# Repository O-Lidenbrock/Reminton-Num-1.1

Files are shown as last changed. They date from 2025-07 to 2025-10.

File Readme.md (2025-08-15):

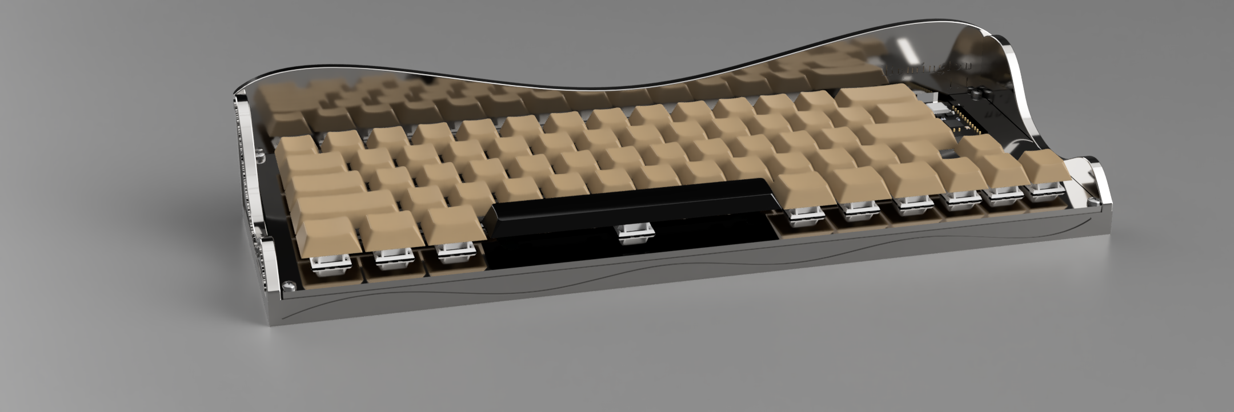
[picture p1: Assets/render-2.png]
Keyboard Render


The Remington #2 was the first typewriter with "macros" - it typed lowercase or uppercase based on whether the user was holding the Shift key. This modern, battery powered keyboard is much smaller and more portable than that original typewriter, but has lost a key. Since this layout is missing the right Shift, it's a version before the Remington #2 - the Remington #1.1

I built this to have a keyboard to use in college. Since it's battery powered, I can throw it in my backpack and use it wherever I'm studying.

> Resubmit Changes:
>
> * Designed a new base to look like a typewriter
> * Found a set of keycaps in a color scheme closer to a typewriter

### BOM

| Item | Qty | Price USD (including shipping) | Link |
|---|-----|---|---|
| Gateron Red Switches x65 | 1 | $21.34 | https://www.aliexpress.us/item/3256805364014141.html |
| Keycaps x65 | 1 | $13.50 | https://www.aliexpress.us/item/3256805435936202.html |
| PCB | 1 | $29.81 | JLCPCB |
| Diodes x65 | 1 | $1.45 | https://www.aliexpress.us/item/3256803242364455.html |
| Nice!Nano V2 | 1 | $25.00 | https://typeractive.xyz/products/nice-nano |
| Stabilizers | 1 | $2.96 | https://www.aliexpress.us/item/3256802930868859.html |
| 3D Printed Case | 1 | Free | Self-printed |
| 601230 3.7V 200mAh Battery | 1 | 12.39 | https://www.aliexpress.us/item/2251832650224851.html |
| M3 Heatset Inserts | 1 | $4.62 | https://www.aliexpress.us/item/3256804442999990.html |
| Nano Headers/Sockets | 1 | Free | From my own stock | 
Total: $111.07 USD

### Schematic
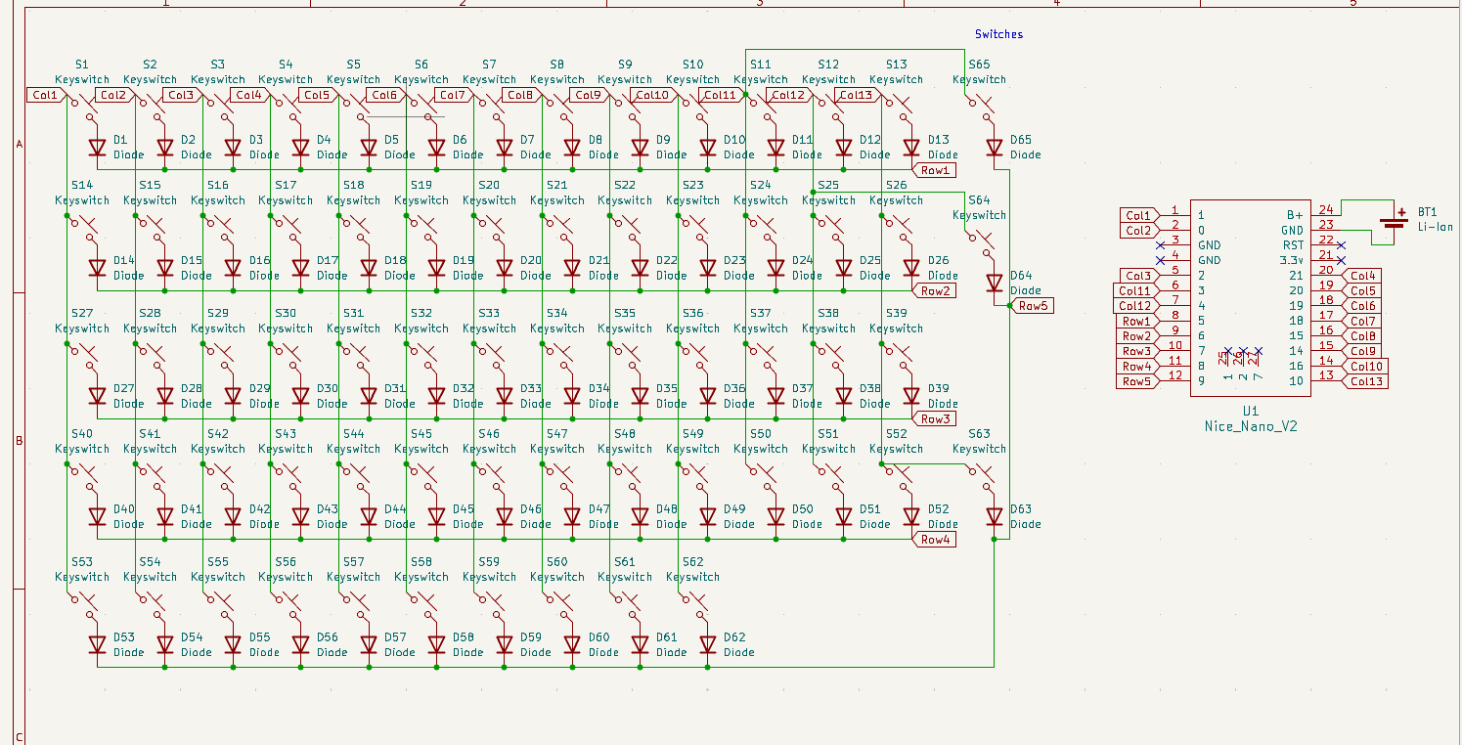
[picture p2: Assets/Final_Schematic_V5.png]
Final_Schematic_V5


### PCB
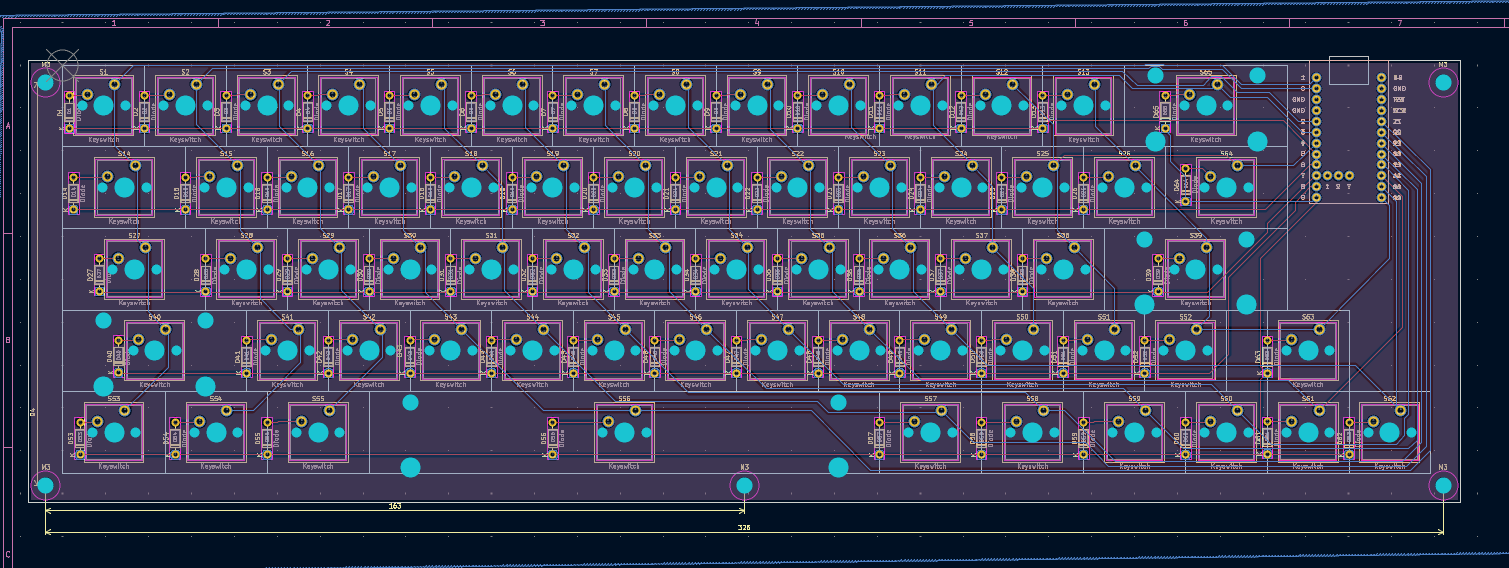
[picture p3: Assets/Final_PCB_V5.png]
Final_PCB_V5


### CAD
Base
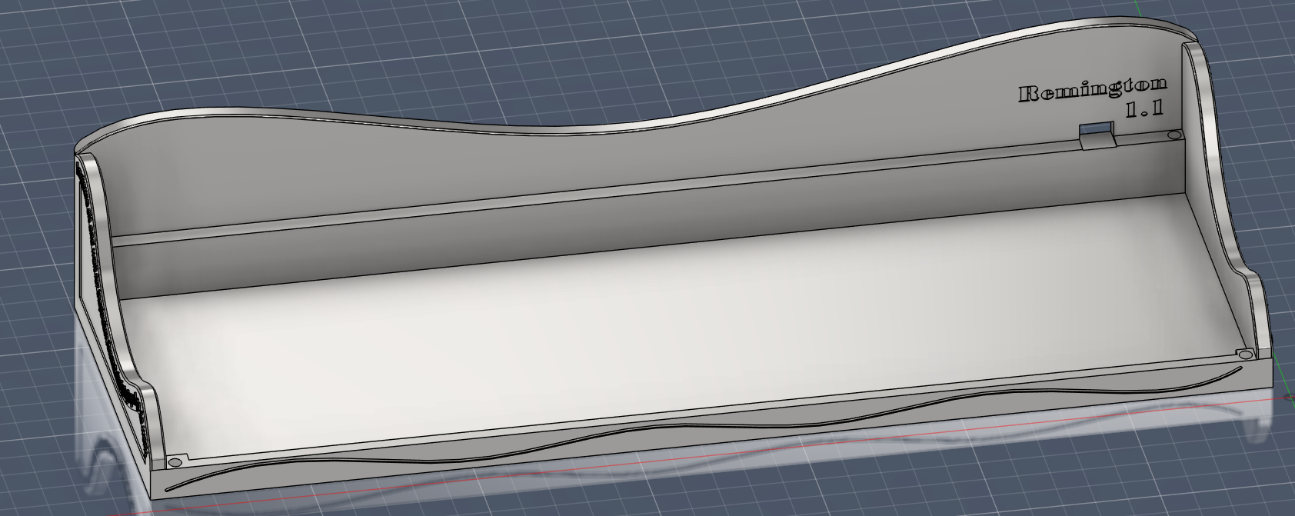
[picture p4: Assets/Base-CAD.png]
Base_CAD


Plate
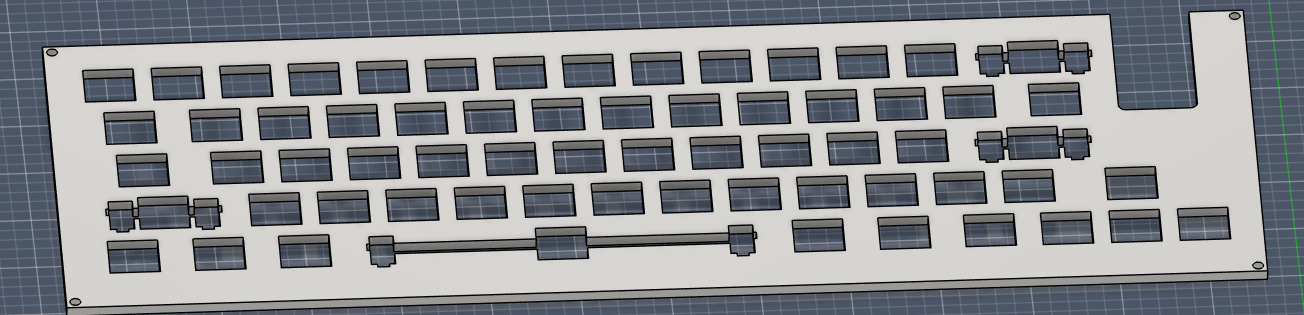
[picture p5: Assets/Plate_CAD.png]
Plate CAD


### Key Layout
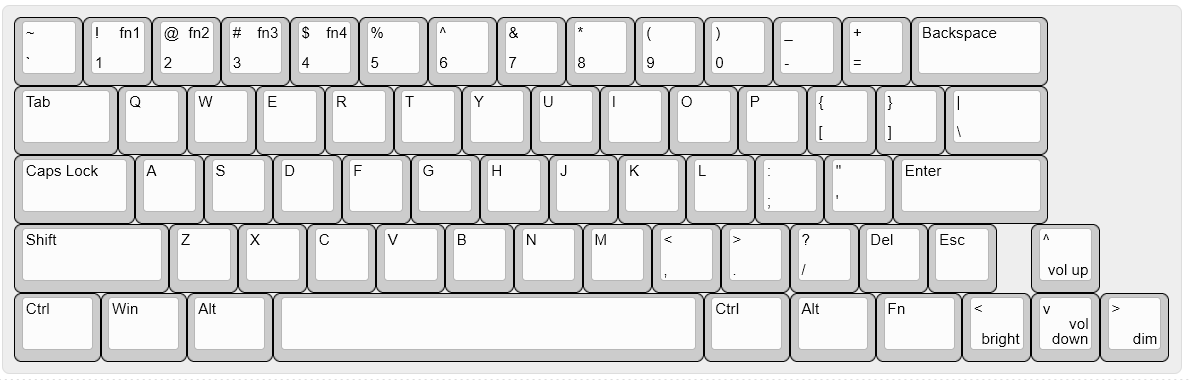
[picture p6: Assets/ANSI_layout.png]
Key layout


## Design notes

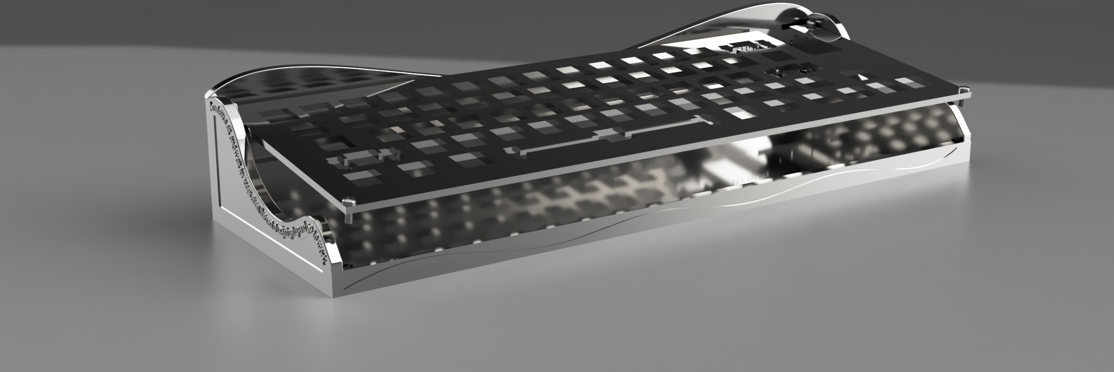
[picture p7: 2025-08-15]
Assets/CaseV4-Render.png

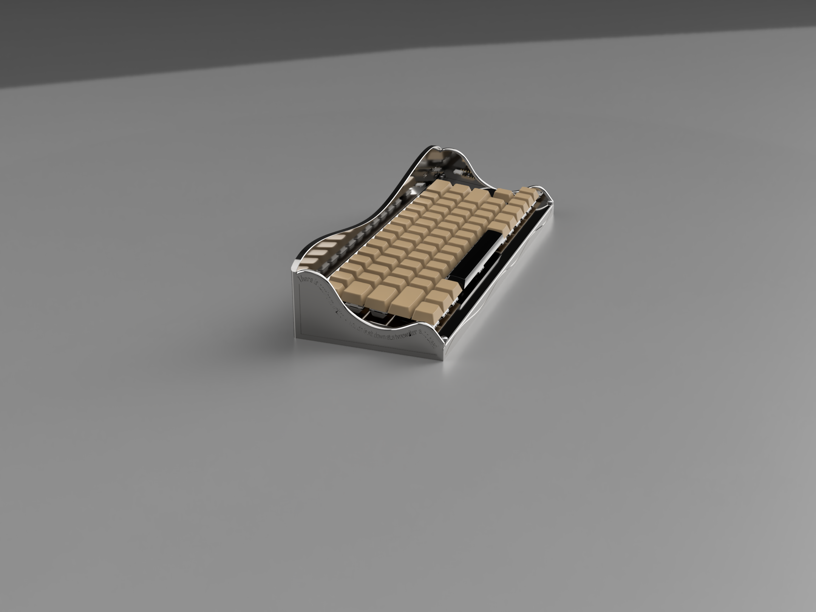
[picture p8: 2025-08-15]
Assets/Side Render.png

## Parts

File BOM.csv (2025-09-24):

Item | Qty | Price USD (including shipping) | Link
Gateron Red Switches x65 | 1 | 21.34 | https://www.aliexpress.us/item/3256805364014141.html
PCB | 1 | 29.81 | JLCPCB
Diodes x65 | 1 | 1.45 | https://www.aliexpress.us/item/3256803242364455.html
Nice!Nano V2 | 1 | 25 | https://typeractive.xyz/products/nice-nano
Stabilizers | 1 | 6.68 | https://www.aliexpress.us/item/3256806342416791.html
3D printed case | 1 | Free | Self-printed
601230 3.7V 200mAh Battery | 1 | 12.39 | https://www.aliexpress.us/item/2251832650224851.html
M3 Heatset Inserts | 1 | 4.62 | https://www.aliexpress.us/item/3256804442999990.html
Keycaps x65 (light brown) | 1 | 13.50 | https://www.aliexpress.us/item/3256805435936202.html
Nano Header | 1 | 1.23 | https://www.aliexpress.us/item/2251800479219321.html

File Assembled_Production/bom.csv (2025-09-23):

Designator | Footprint | Quantity | Value | LCSC Part #
D1, D10, D11, D12, D13, D14, D15, D16, D17, D18, D19, D2, D20, D21, D22, D23, D24, D25, D26, D27, D28, D29, D3, D30, D31, D32, D33, D34, D35, D36, D37, D38, D39, D4, D40, D41, D42, D43, D44, D45, D46, D47, D48, D49, D5, D50, D51, D52, D53, D54, D55, D56, D57, D58, D59, D6, D60, D61, D62, D63, D64, D65, D7, D8, D9 | D_SOD-123 | 65 | Diode
S1, S10, S11, S12, S13, S15, S16, S17, S18, S19, S2, S20, S21, S22, S23, S24, S25, S26, S28, S29, S3, S30, S31, S32, S33, S34, S35, S36, S37, S38, S4, S41, S42, S43, S44, S45, S46, S47, S48, S49, S5, S50, S51, S52, S6, S60, S61, S62, S63, S7, S8, S9 | SW_Cherry_MX_1.00u_PCB | 52 | Keyswitch
S14, S64 | SW_Cherry_MX_1.50u_PCB | 2 | Keyswitch
S27 | SW_Cherry_MX_1.75u_PCB | 1 | Keyswitch
S39, S40 | SW_Cherry_MX_2.25u_PCB | 2 | Keyswitch
S53, S54, S55, S57, S58, S59 | SW_Cherry_MX_1.25u_PCB | 6 | Keyswitch
S56 | SW_Cherry_MX_6.25u_PCB | 1 | Keyswitch
S65 | SW_Cherry_MX_2.00u_PCB | 1 | Keyswitch
U1 | Nice_Nano_V2 | 1 | Nice_Nano_V2

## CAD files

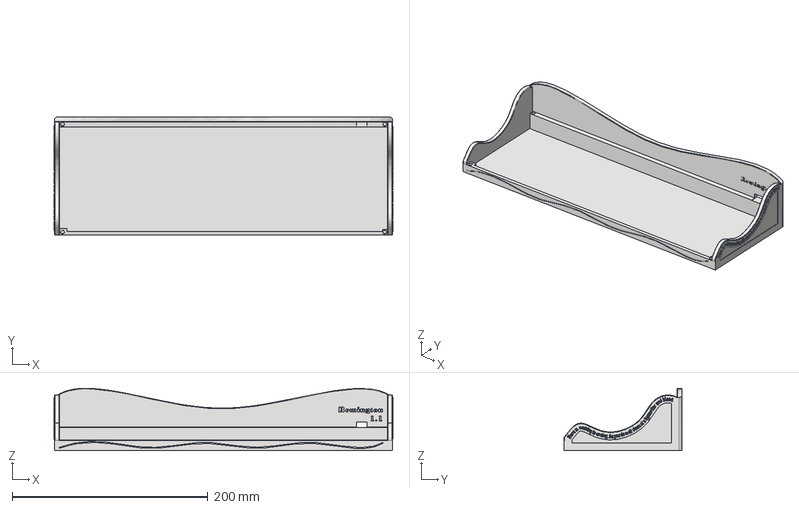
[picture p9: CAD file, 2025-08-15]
Production/Base V4 Typewriter.step
346.0 x 120.5 x 63.6 mm

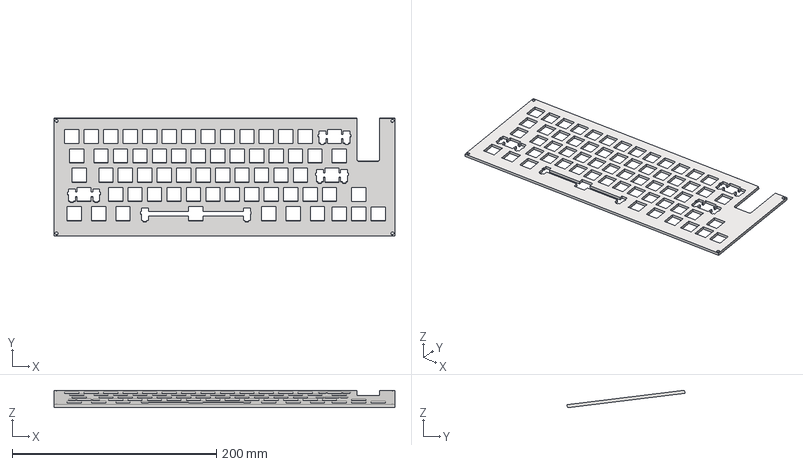
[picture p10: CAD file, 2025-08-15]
Production/Plate.step
334.0 x 115.5 x 17.1 mm

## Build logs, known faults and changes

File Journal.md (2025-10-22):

---
title: "Remington 1.1"
author: "Stephen McAllister"
description: "Custom keyboard layout: 60% with arrow keys. BLE and battery-powered."
created_at: "2025-07-03"
---

> 📘 Total Time:  33.5 hours

#### 7_3_2025 Design key layout

*1.2h* I want this to be a very small, BLE enabled, battery powered keyboard. I like the Drop Alt board design, so I'm aiming for something like that.

Getting full arrow keys (where the up/down keys aren't .5u tall) wreaks havoc with spacing. I got rid of the right shift key. 

Having func keys tertiary to the num row is fine, but I want a completely seperate esc and del key, so dropped those on the right near the arrow keys. In a final version those might just be macros.

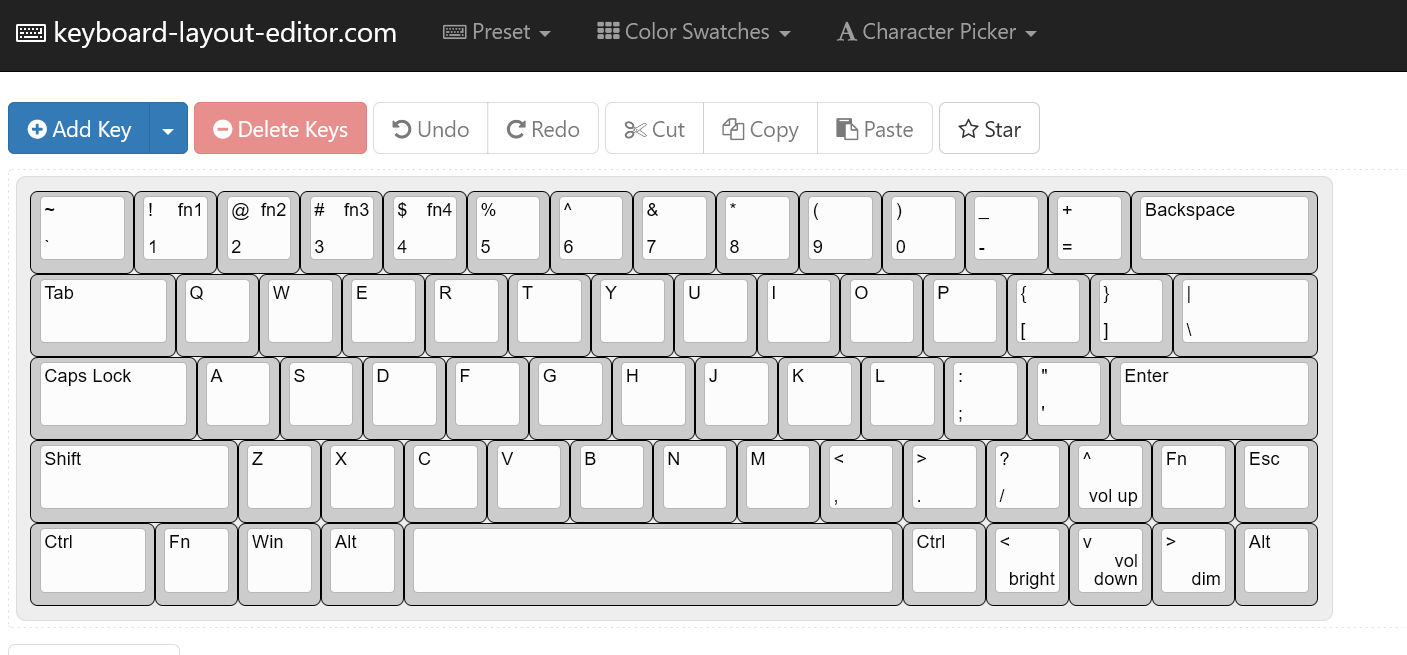
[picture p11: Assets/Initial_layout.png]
Initial Keyboard Layout


---

#### 7_15_2025 Schematic + PCB V1

*1h* Started this by laying out the switches and diodes on the schematic. I layed them out in a 14 x 5 grid, then deleted switches from the rows with fewer keys: 
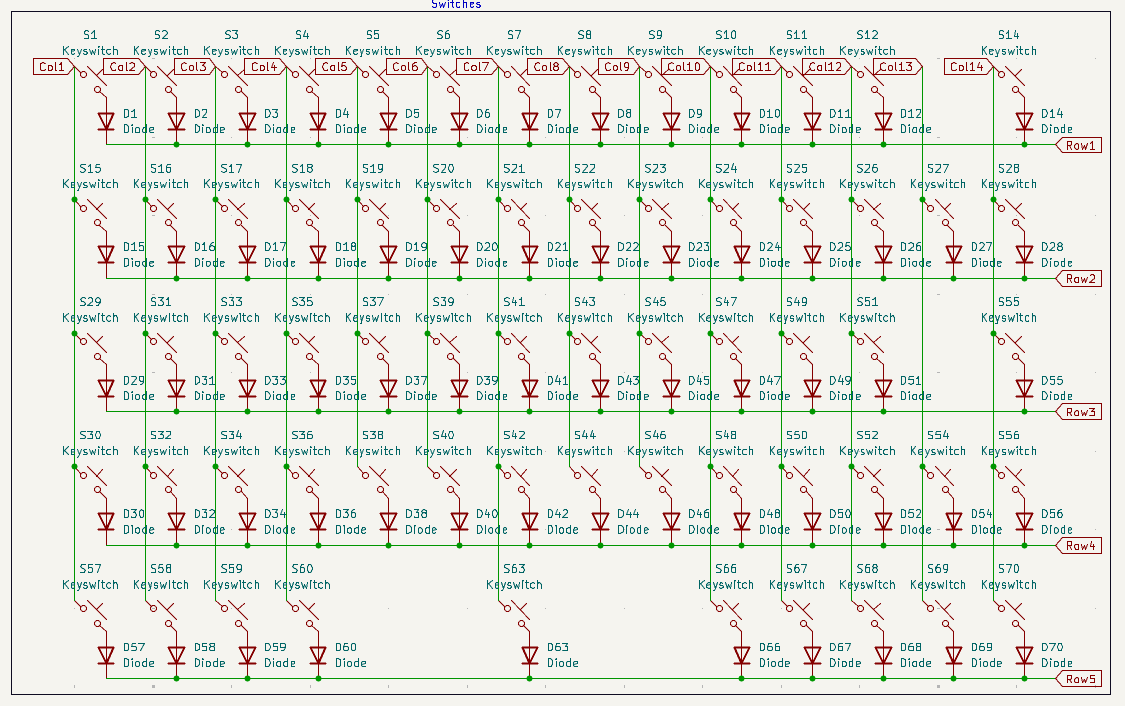
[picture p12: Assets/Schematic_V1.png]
Schematic Version 1


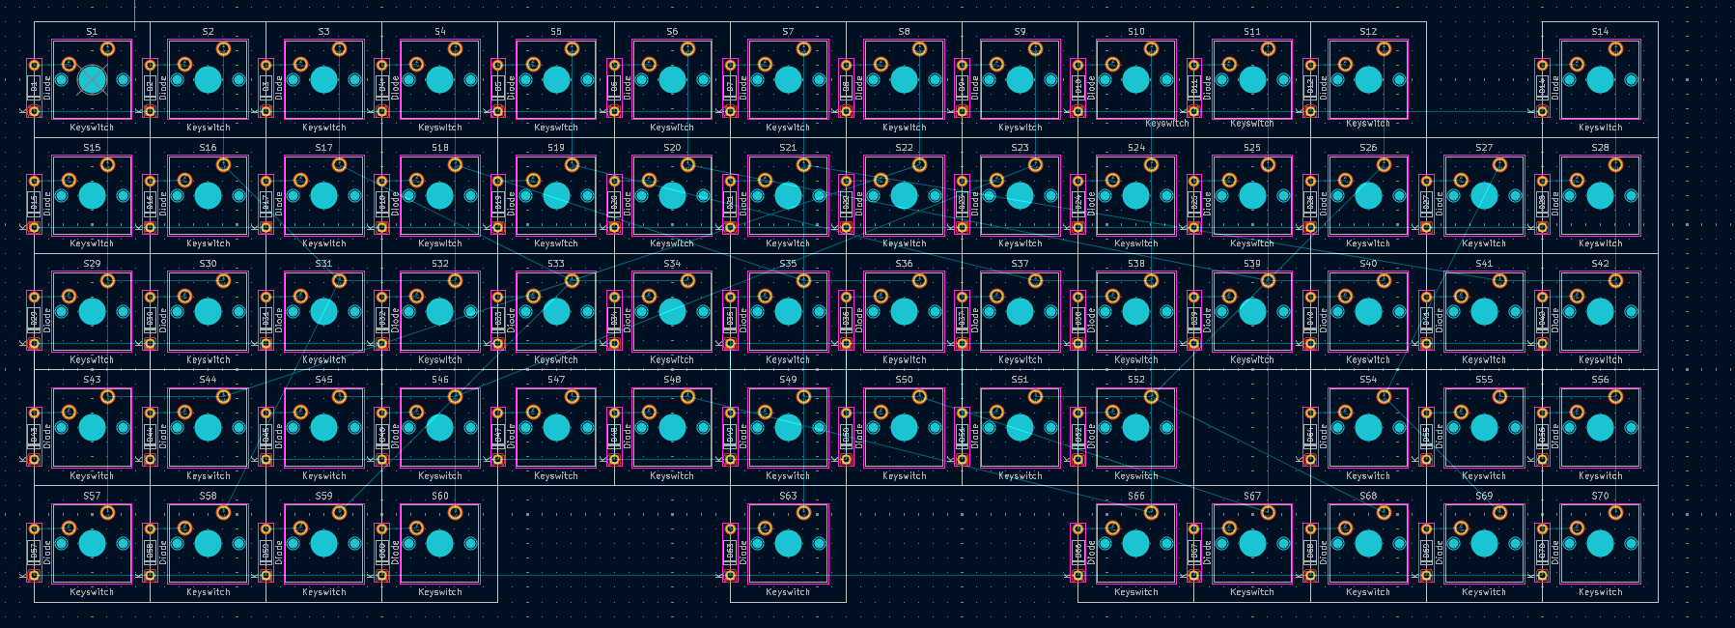
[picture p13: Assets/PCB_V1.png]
PCB Version 1
*1.5h* Once I figured out how to move the symbols on the right grid (drag them from the center pad), moving these around was pretty easy. Unfortunately I turned off the ratnest, and when I turned it back on realized the numbering was off. KiCad numbered my switches oddly when I copied and pasted on the schematic, so the last three rows of keys are all messed up. Problem for next time. 

---

#### 7_19_2025 Schematic + PCB V2

*20m* Rewrote the schematic of the switches with the right numbering. I also realized I needed one more switch in the top row, so added that. Now that I know what I'm doing, it took a lot less time.
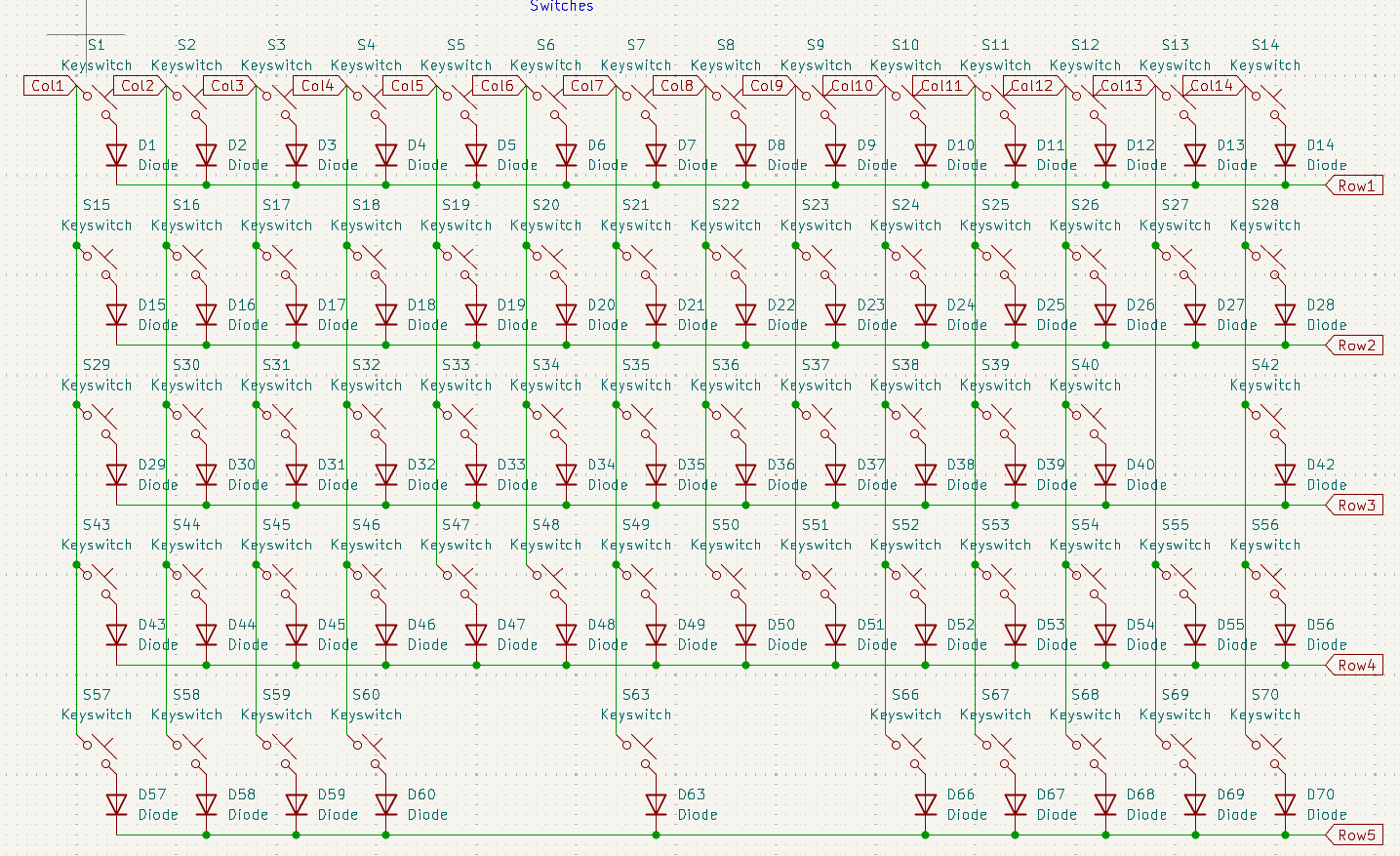
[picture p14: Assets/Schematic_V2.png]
Schematic Version 2


*4m* Updated the PCB and every switch moved to the right place! Only 13 and 53 needed to be placed. In this process I realized my original schematic was also missing switch 53, so placed that.

*20m* Change the key sizes  
I went through the schematic and changed the footprint key sizes. That's when I [found out](https://hirosarts.com/blog/keycap-dimensions-guide-for-beginners/?) that a 2.5u Shift and Caps Lock key is very hard to come by for ANSI keyboard keycap sets. I still want this pretty small, but I'll need a place for the Nano anyway, so I'm going to add the Nano to the PCB and see how the spacing works out.

*54m* Research controller boards  
This board needs bluetooth (esp32), enough pins, well-documented, and cheap. I could try a SEEED board but I'd like some arduino experience so I'm doing the Nano Esp32 with a step-up. There's also this image on one of the [docs](https://docs.arduino.cc/tutorials/nano-esp32/cheat-sheet/) showing a possible direct power from battery option. It needs EXACTLY 3.3v, though, and disables the usb-c power, so I guess I'd need a step-down in my schematic. I'll figure this out after - I know the Nano is the board I want.

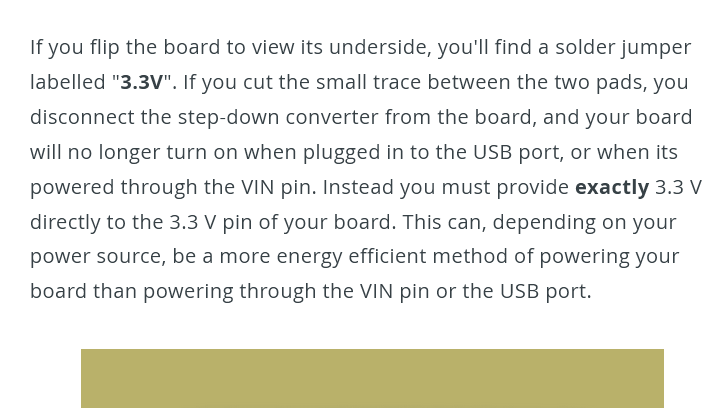
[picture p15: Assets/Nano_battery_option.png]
Arduino docs screencap


#### 7_20_2025 Schematic + PCB V3

*1.5h* Many of my keys are non-standard sizes, like the enter and caps lock which I made 2.5u. It's cheaper to buy ANSI keycaps, so I rewrote the board based on ANSI sizes. The arrows stick out, but I need a place for the board anyway so it's fine. New layout:
New ANSI Safe layout

*1h* Researched some more, and found out the Nice!Nano V2 is a very popular chip for wireless boards. Read for a while about connecting it to batteries and such.

*3h* Sooo the Nice nano only has 18 GPIO pins and I have 14 columns + 5 rows = 19 pins needed. However, I only need 65 keys: 13*5. So I'm deleting the final row and moving the keys where I need them.
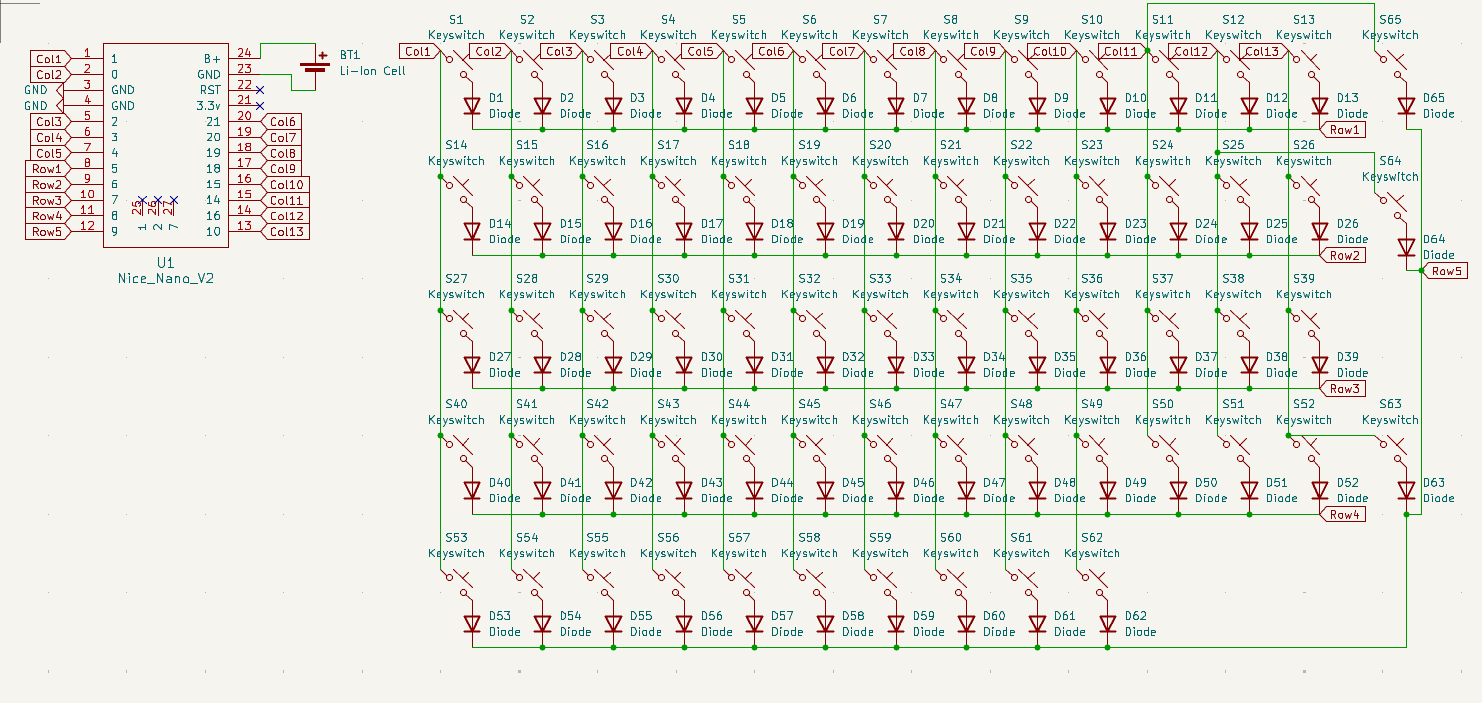
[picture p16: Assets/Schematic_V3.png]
Schematic Version 3, now 13x5


With 13 columns and 5 rows, I use all the pins. It took a while to route the individual keys, and tomorrow I'll finish by connecting lines to the board. Might need to shuffle around things to keep the rat's nest simpler.
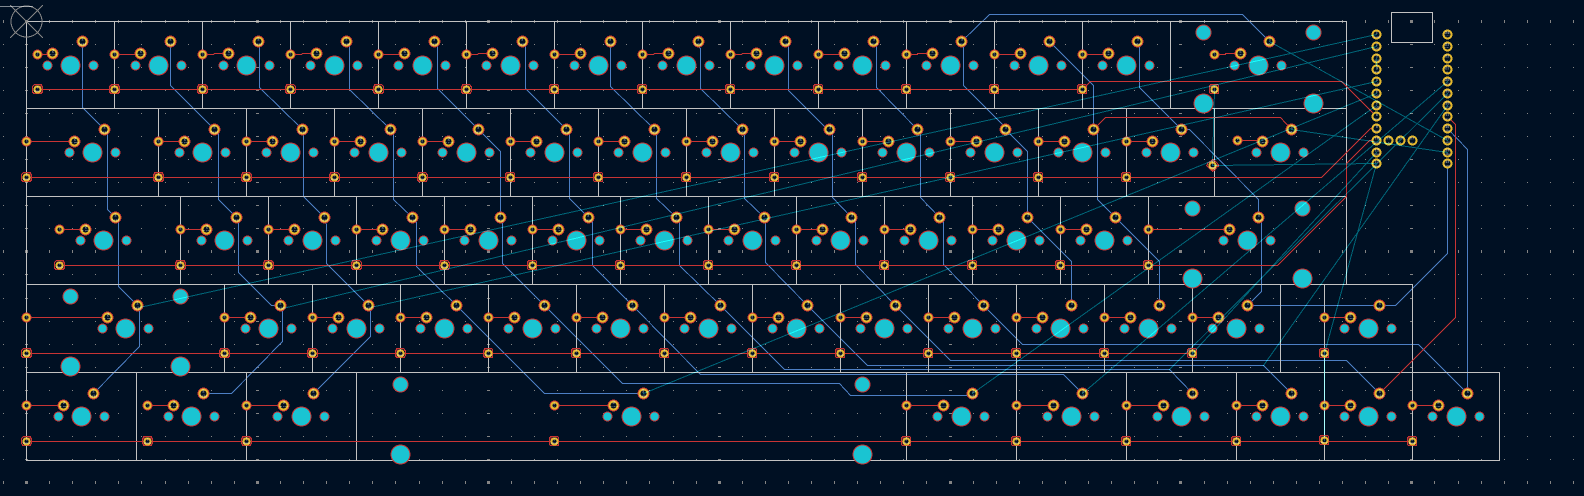
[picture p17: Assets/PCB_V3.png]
PCB editor screenshot with col and rows routed


#### 7_23_2025

*20min* Connected ratsnest to the board. It's a bit messy - might be worth shifting around pins and things.

#### 7_23_2025 Finish PCB

*1h* Fixed the ratsnest. Gave the wires correct clearance and tightened up the edges of the PCB. The stabilizer holes on the backspace button are in a really annoying position, but got around them eventually.
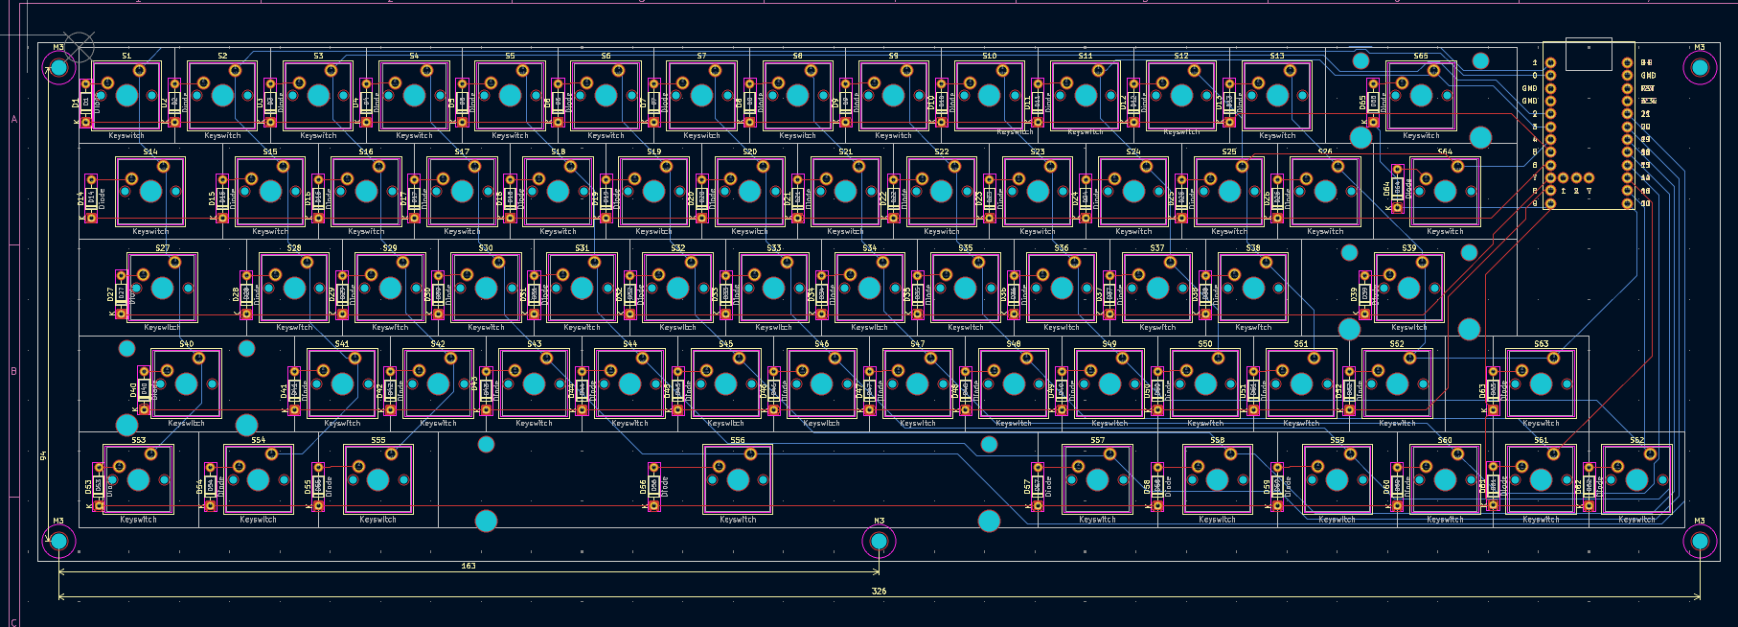
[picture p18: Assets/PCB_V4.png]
Completed PCB Wiring


#### 7_27_2025 Finish CAD

*2h* Fought with the switch model for a while, trying to figure out configurations. The final switch model has a configuration for each size of keycap, which makes it easy to switch them around on the board design. Next time I try this it will go faster
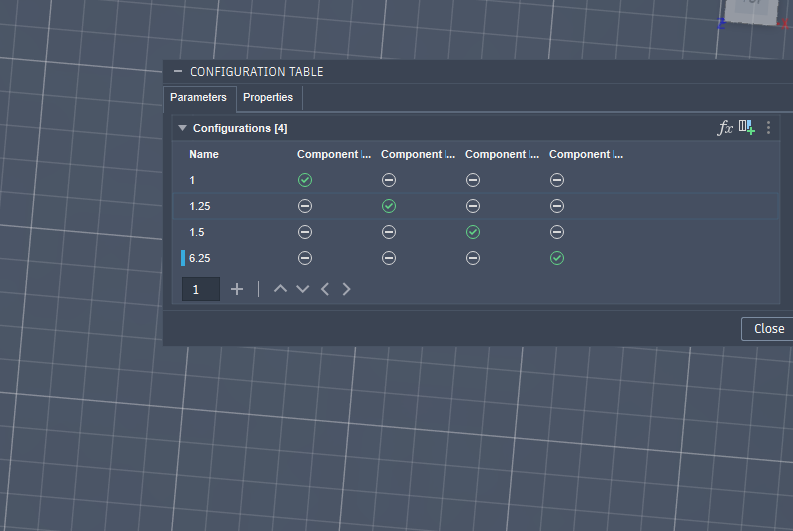
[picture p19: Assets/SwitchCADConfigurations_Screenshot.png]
Switch Configurations


*1.5h* Making the base and lid was straightforward. Deciding on a height for the base took a bit - I used my completed macropad to estimate how high on the switch the base should be, then extruded it to that plane in F3D. The PCB sits on a little ledge + has 5 mounting holes.
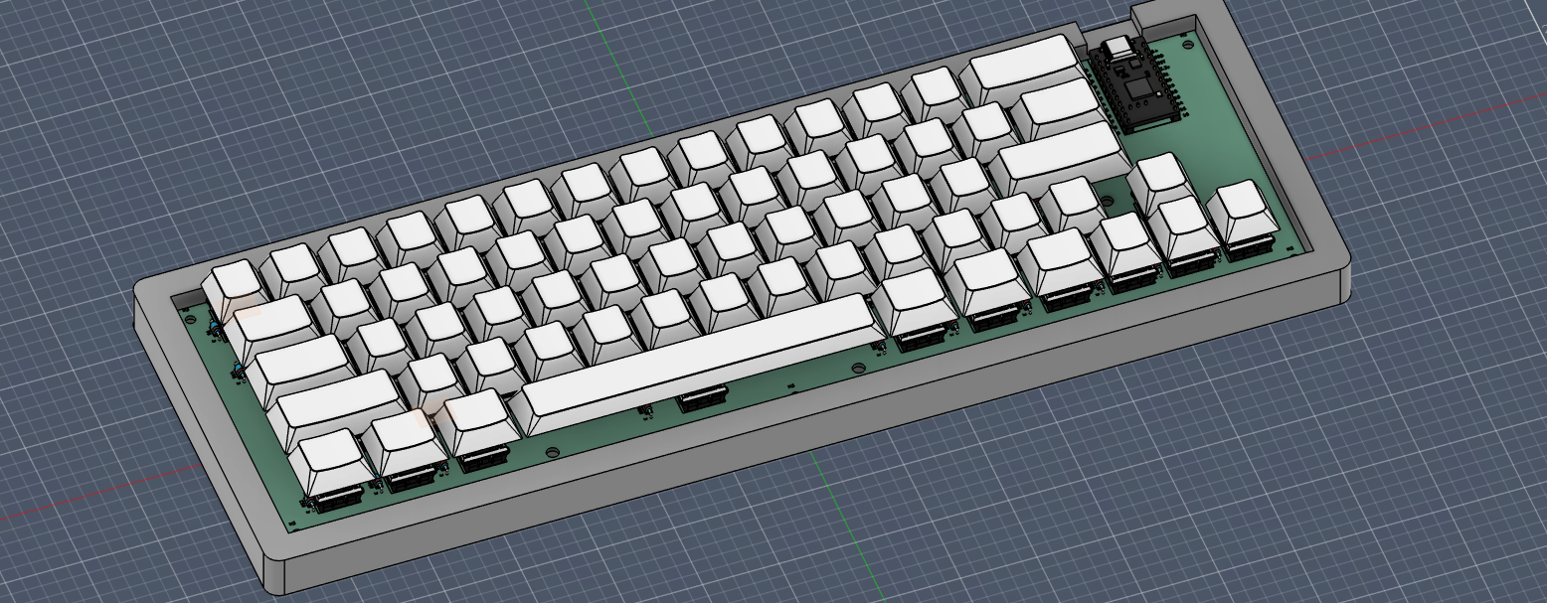
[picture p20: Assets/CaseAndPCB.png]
Case Base w/ PCB


#### 7_28_2025 Completing

*1h* Realized the support ledge interfered with the Nano pins and a stabilizer, so went back and changed the sketch. Sometimes Fusion's history is very useful. Also added mounting holes: I'm using all M3 heatset mounts everywhere.

Added a ground plane (not connected to anything tho bc this is battery powered)

*1h* Recheck board, generate gerbers, put all my files in the repo

*45m* Create BOM and find all the parts.

*30m* Write Firmware

*45m* Finish Journal + Readme + submit project

#### 7_31_2025

*2h* Switched the case design to something that looks more like the original typewriters. Picked a set of tan keycaps to match.
Most of the work was getting the spline to extrude nicely over the supports. 
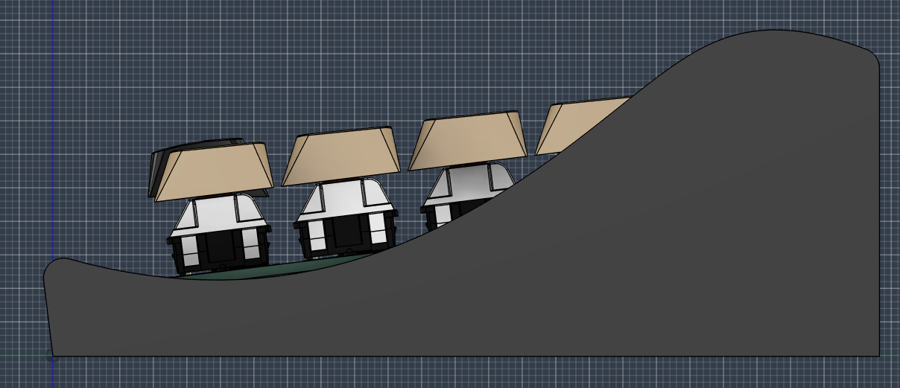
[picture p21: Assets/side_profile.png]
Side Profile


I tilted the board 7 degrees to make typing easier.
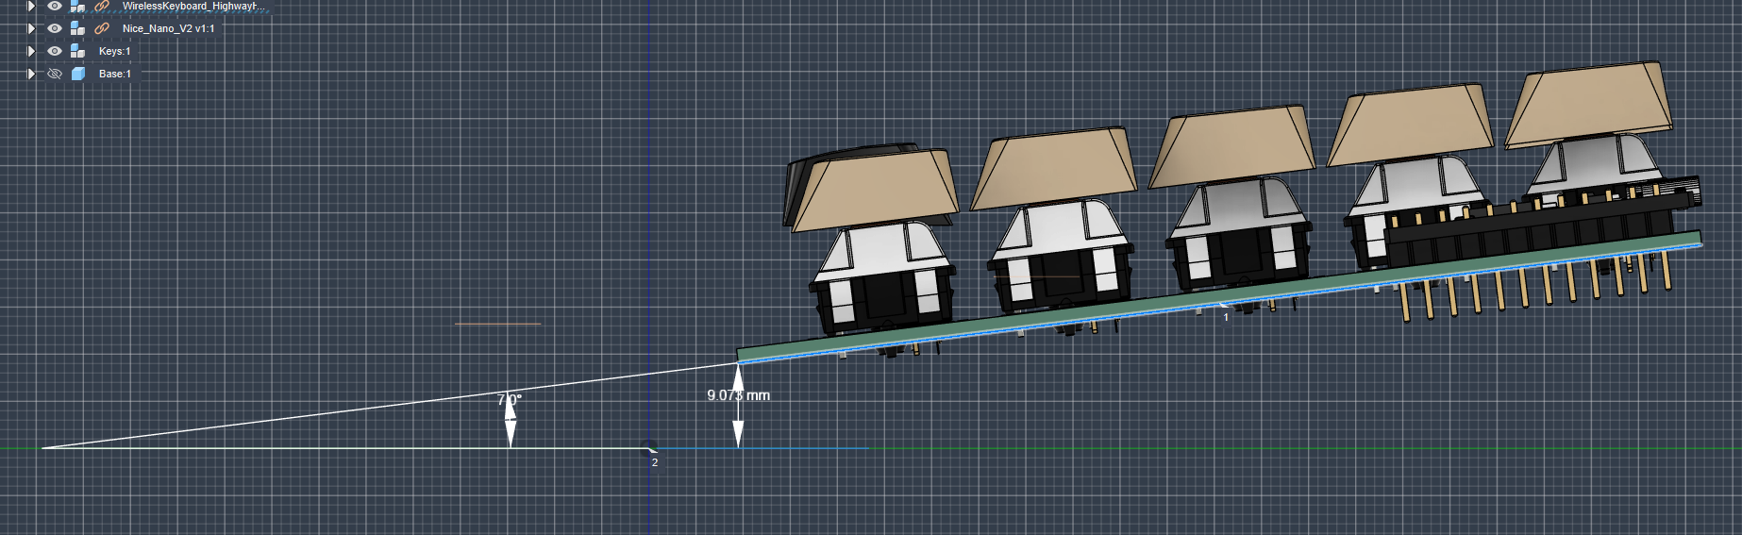
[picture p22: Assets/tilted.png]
Tilted Board


This is the final base I got, but feedback on the server was that it still isn't complex enough. Next move: add a plate and keep modifying the case. I think I'll need to completely rebuild the model.
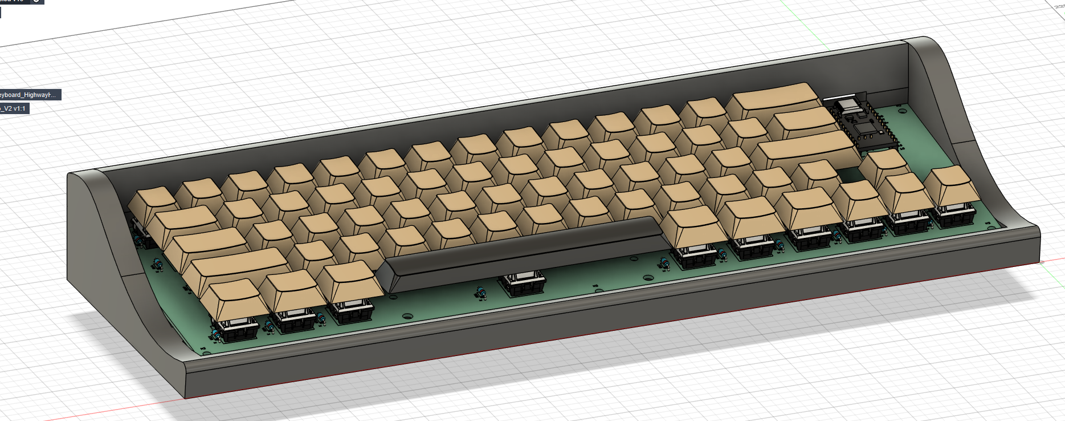
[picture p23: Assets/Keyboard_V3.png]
Keyboard_V3


#### 8_8_2025

*4h* I rebuilt the case to use a plate mount instead of screwing the pcb in (left the pcb drill holes in case I change it in the future.) To rebuild the case, I started with a side profile and a base:
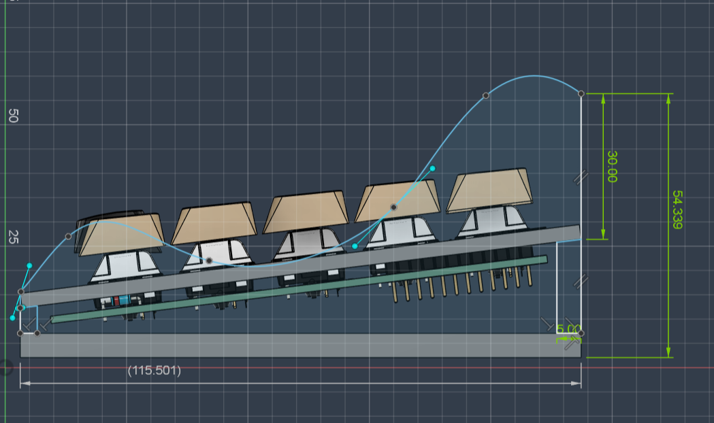
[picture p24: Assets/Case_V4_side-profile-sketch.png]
Side profile sketch


Off of this side profile, I designed a bottom base that supports the plate and has the decorative sides. 
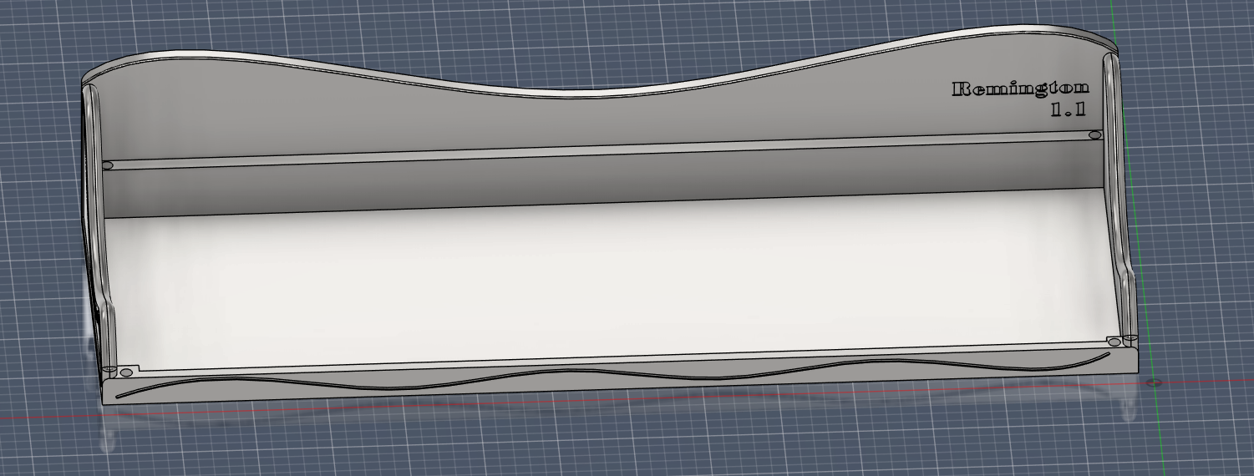
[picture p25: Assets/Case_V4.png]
Case Bottom

I watched this ScottoKeebs video to get an idea of how to design the plate: https://www.youtube.com/watch?v=7azQkSu0m_U

Then, I designed a plate that bolts in with M3 screws and inserts.  
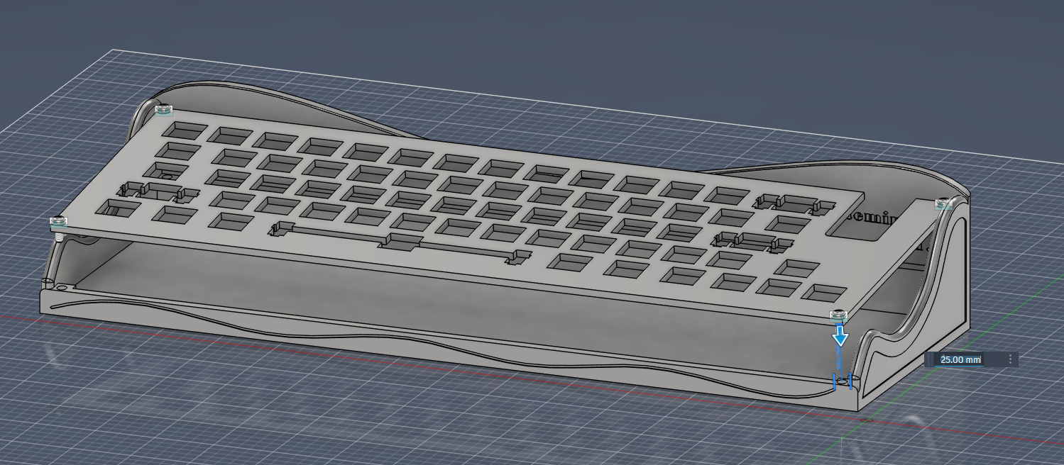
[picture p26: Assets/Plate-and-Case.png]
Plate-and-Case


#### 8_15_2025

*30m* Added some quotes and a depressed profile on both sides. Left is Stephen King and right is Ernest Hemingway.  
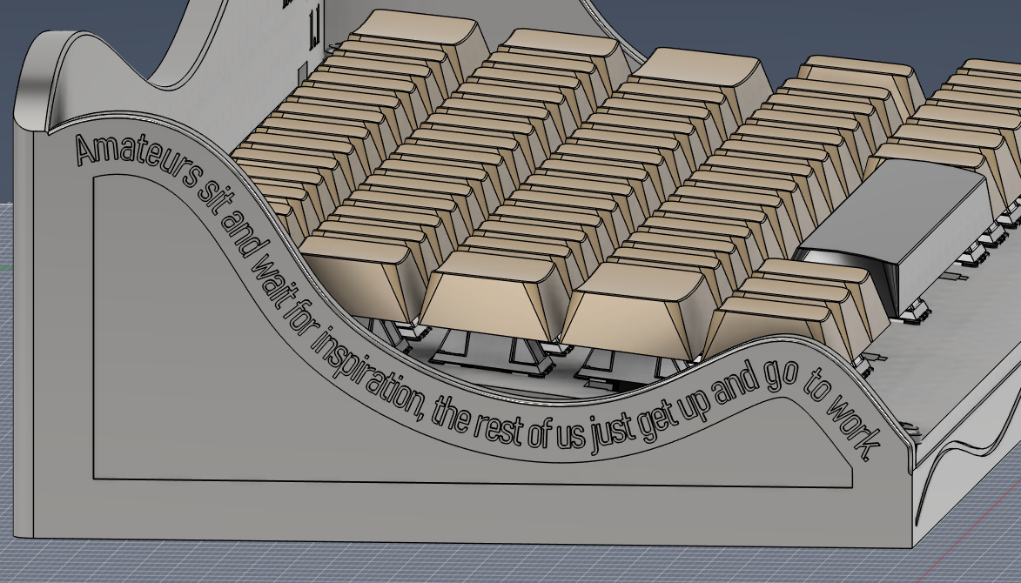
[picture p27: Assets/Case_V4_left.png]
Case Left
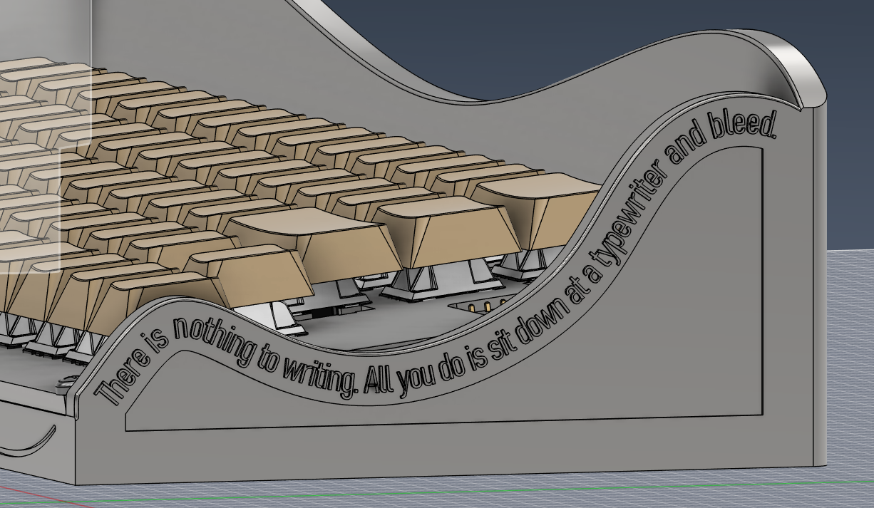
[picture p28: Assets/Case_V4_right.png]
Case Right
  

*30m* Catch up Journal and submit.

#### 9_17_2025

*15m* Find some SMD diodes that will work for cheap assembly from JLC (Part #C8598)
*30m* rewire the PCB with said diodes. They use a SOD-123 footprint.
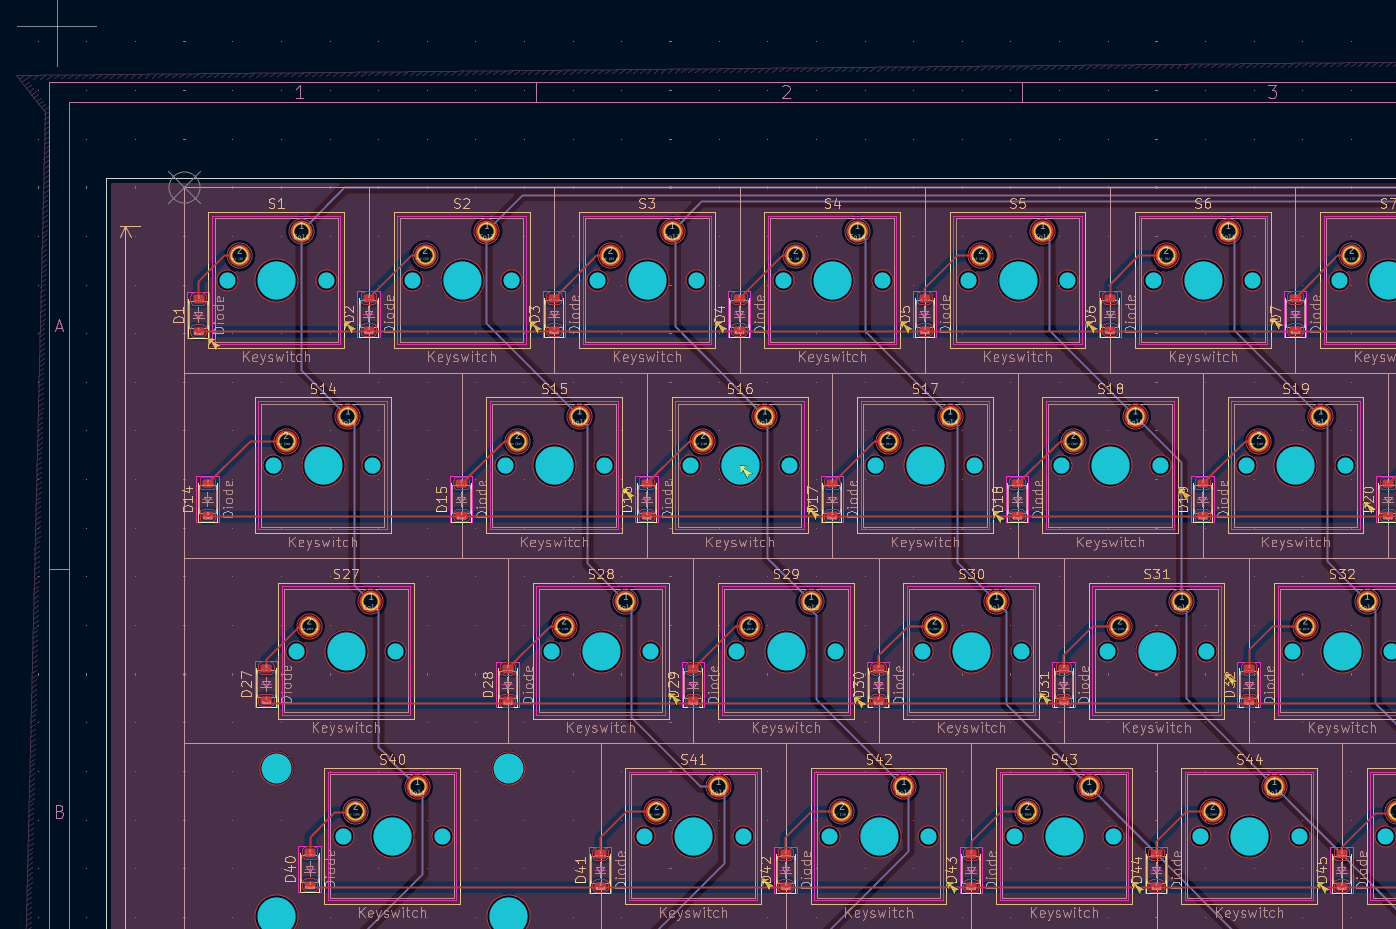
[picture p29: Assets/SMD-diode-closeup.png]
SMD Diode closeup


#### 9_20_2025

*2h* Figure out how to write a BOM and pick and place file from KiCad. I ended up using the defaults generated by KiCad, then uploaded those to KiCad after selecting "PCB Assembly." Then, I looked up the cheap Schottky diodes and replaced whatever was in the BOM with those, and selected DNP for everything else. I used 

It ended up being $15 more expensive than just soldering the diodes myself, so I'm not going to use these files. I'll stick with the old setup in the Production folder.

#### 9_23_2025

*20m*
* Check all BOM links and update prices
* find some decent headers for my Nano
* text my reviewer to check that adding headers to my BOM is good:
Changes:
> Added headers for
> Stabilizers can't be shipped, went from $2.96 to $6.68

*30m* Start ordering

#### 10_13_2025

*2hr* Begin build. I realized these keyswitches are three prong instead of 5 prong, so the plate will have to do the alignment and stabilization. The makerspace only has 3mm acrylic and the plate clips on the switches are 1.5mm so I need to figure out what to do there.

3d printed two different test pieces, to see how the switches and keycaps will fit. Realized my stabilizers don't fit the normal stabilizer hole, so I added a few mm on each side to let the stabs all the way through the plate. Lasered a test in 3mm acrylic and it worked.

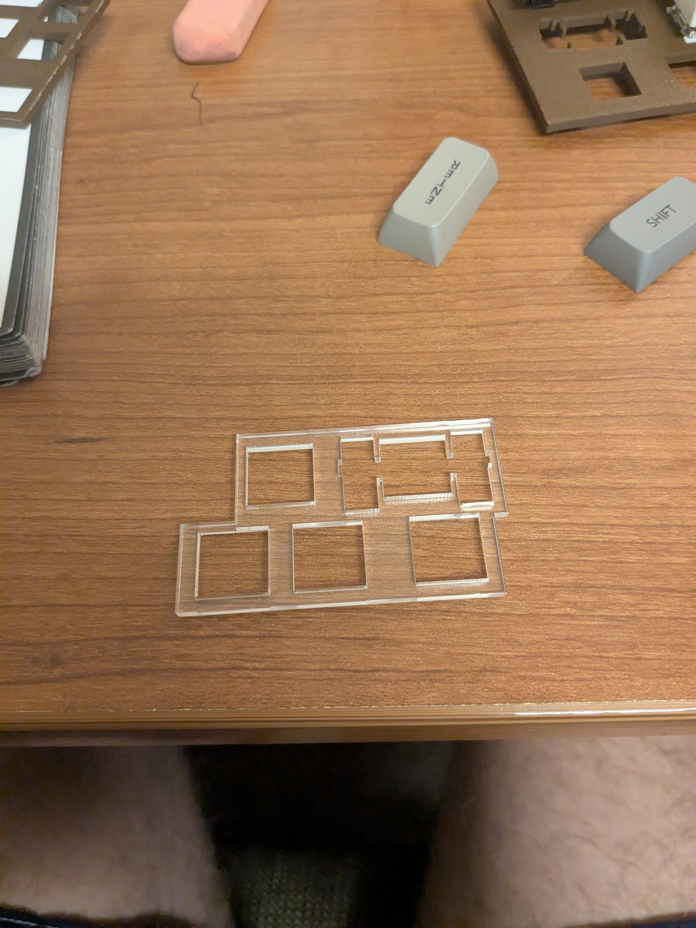
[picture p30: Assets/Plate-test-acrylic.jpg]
Acrylic Plate Test Piece

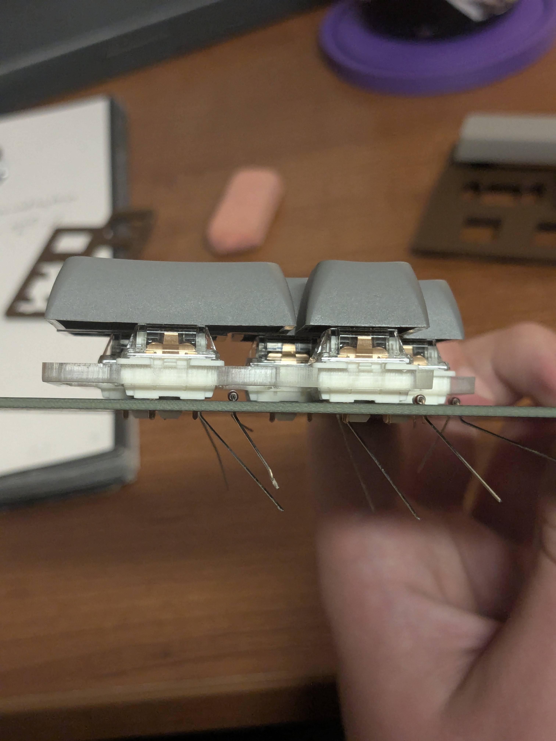
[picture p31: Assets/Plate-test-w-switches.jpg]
Plate test piece with switches

#### 10_14_2025

*1h* Start soldering in diodes on the board.

#### 10_15_2025

*3h* Laser the full plate (with extended stab holes), solder in some of the switches. Keeping them flush while soldering is hard, I'm soldering some in, then holding the board upright and remelting the solder to shove the switch in more.

#### 10_16_2025

*2h* Finished soldering in all the switches

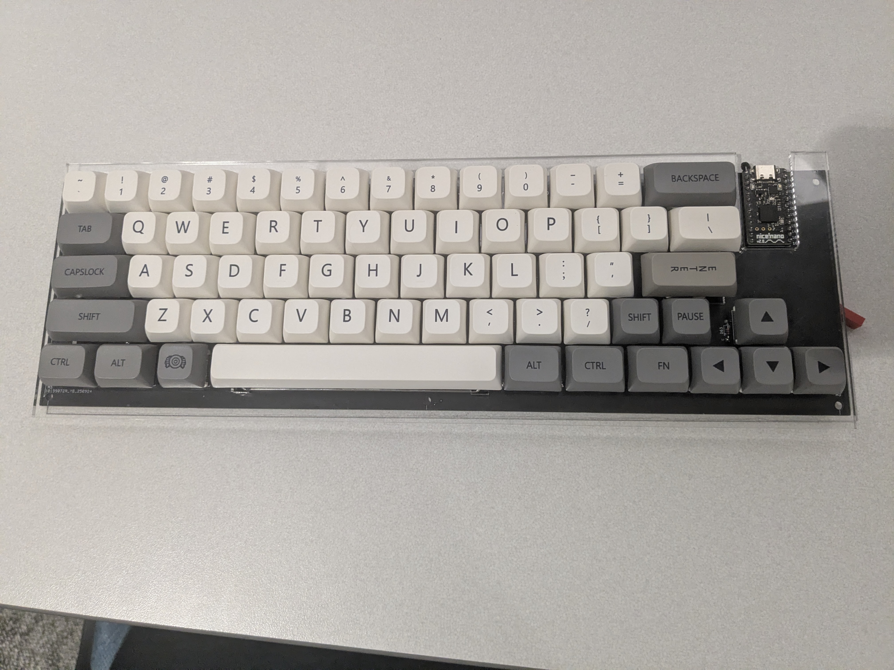
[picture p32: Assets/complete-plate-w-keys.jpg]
Completed Plate with switches


*1h* Fought with a JST RCY connector to get the battery connected to the NiceNanov2
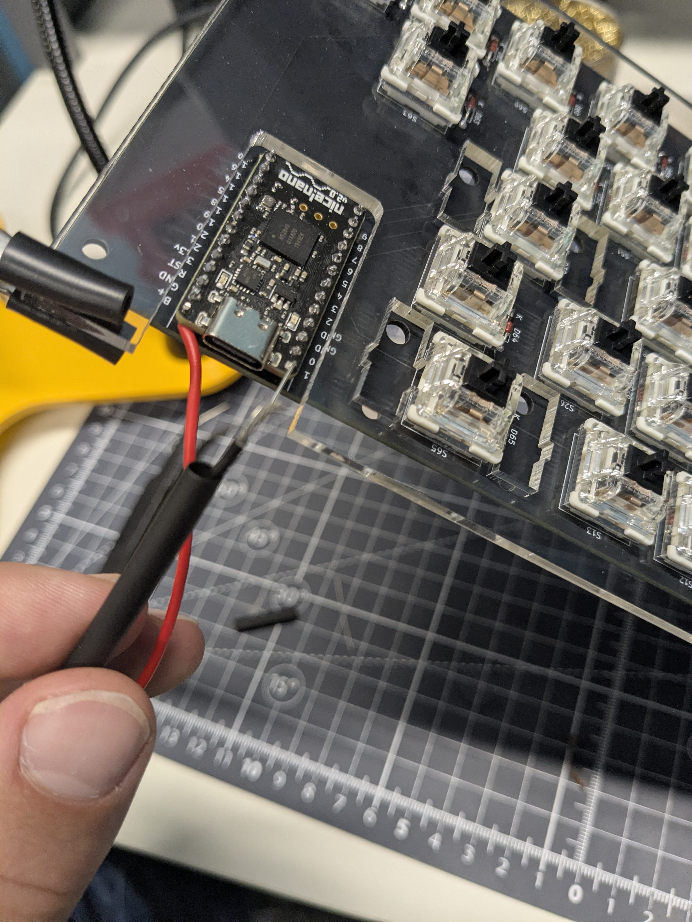
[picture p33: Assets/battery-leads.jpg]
Battery Leads soldered to Nice Nano


#### 10_20_2025

*1h* Tried to write the firmware. Using AI bc ZMK docs are confusing

*1h* Fixed the code bc the AI can't write keymaps or shields. Got a custom shield written

#### 10_21_2025

*20m* Fixed the keymap and finished the build process. Ready to flash the keeb

*2.2h* 
Switched to row2col and it crashed out, I think it typed every key. So the computer crashed out. The other option is I have a short in one of the matrix rows, probably the last one, but it's typing numbers too so idk.

It connected to BT but wouldn't type, so I enabled logging in the build.yaml file with ```snippet: zmk-usb-logging```

I installed PutTTy for debugging

Pulled the switches high instead of low and it works (some keys don't fire but that's a matrix issue)

Realized the entire row five wasn't working using Putty. Checked the traces on the pcb and in KiCad, so it must be an overlay problem. Had the wrong pin marked (16 when it was 06)

Fought with flipping around a bunch of keys before i realized I just had three column pins flipped around.
WORKS!

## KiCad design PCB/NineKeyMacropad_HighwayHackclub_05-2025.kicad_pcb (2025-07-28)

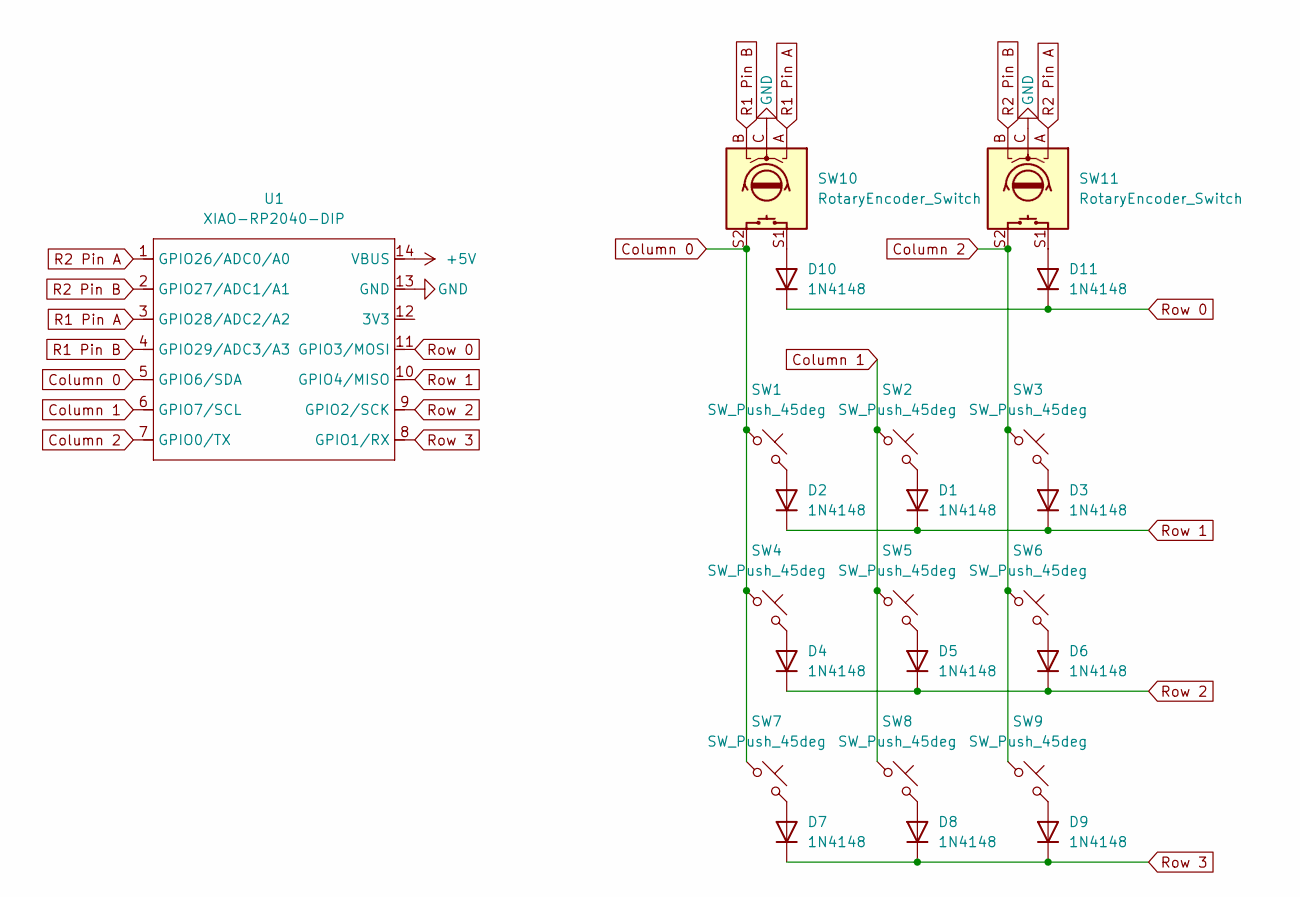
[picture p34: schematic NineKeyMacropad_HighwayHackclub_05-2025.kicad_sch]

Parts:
D1, D2, D3, D4, D5, D6, D7, D8, D9, D10, D11: 1N4148; D_DO-35_SOD27_P7.62mm_Horizontal
SW1, SW2, SW3, SW4, SW5, SW6, SW7, SW8, SW9: SW_Push_45deg; SW_Cherry_MX_1.00u_PCB
SW10, SW11: RotaryEncoder_Switch; RotaryEncoder_Alps_EC11E-Switch_Vertical_H20mm
U1: XIAO-RP2040-DIP

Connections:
+5V: U1.14 (VBUS)
Column 0: SW1.1, SW4.1, SW7.1, SW10.S2, U1.5 (GPIO6/SDA)
Column 1: SW2.1, SW5.1, SW8.1, U1.6 (GPIO7/SCL)
Column 2: SW3.1, SW6.1, SW9.1, SW11.S2, U1.7 (GPIO0/TX)
GND: SW10.C, SW11.C, U1.13 (GND)
unnamed: D1.2 (A), SW2.2
unnamed: D2.2 (A), SW1.2
unnamed: D3.2 (A), SW3.2
unnamed: D4.2 (A), SW4.2
unnamed: D5.2 (A), SW5.2
unnamed: D6.2 (A), SW6.2
unnamed: D7.2 (A), SW7.2
unnamed: D8.2 (A), SW8.2
unnamed: D9.2 (A), SW9.2
unnamed: D10.2 (A), SW10.S1
unnamed: D11.2 (A), SW11.S1
R1 Pin A: SW10.A, U1.3 (GPIO28/ADC2/A2)
R1 Pin B: SW10.B, U1.4 (GPIO29/ADC3/A3)
R2 Pin A: SW11.A, U1.1 (GPIO26/ADC0/A0)
R2 Pin B: SW11.B, U1.2 (GPIO27/ADC1/A1)
Row 0: D10.1 (K), D11.1 (K), U1.11 (GPIO3/MOSI)
Row 1: D1.1 (K), D2.1 (K), D3.1 (K), U1.10 (GPIO4/MISO)
Row 2: D4.1 (K), D5.1 (K), D6.1 (K), U1.9 (GPIO2/SCK)
Row 3: D7.1 (K), D8.1 (K), D9.1 (K), U1.8 (GPIO1/RX)

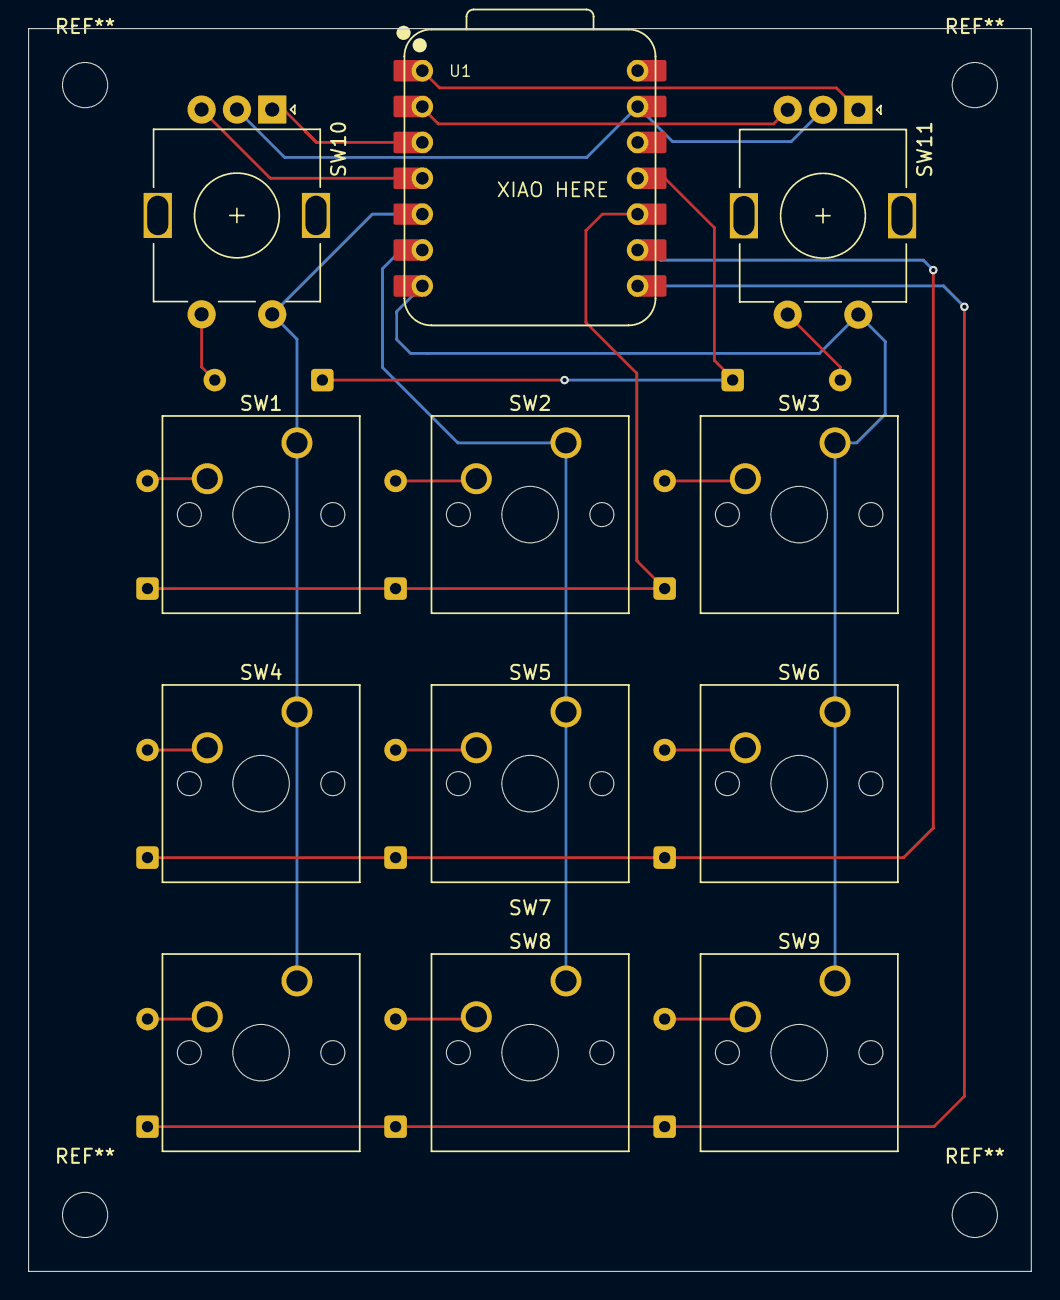
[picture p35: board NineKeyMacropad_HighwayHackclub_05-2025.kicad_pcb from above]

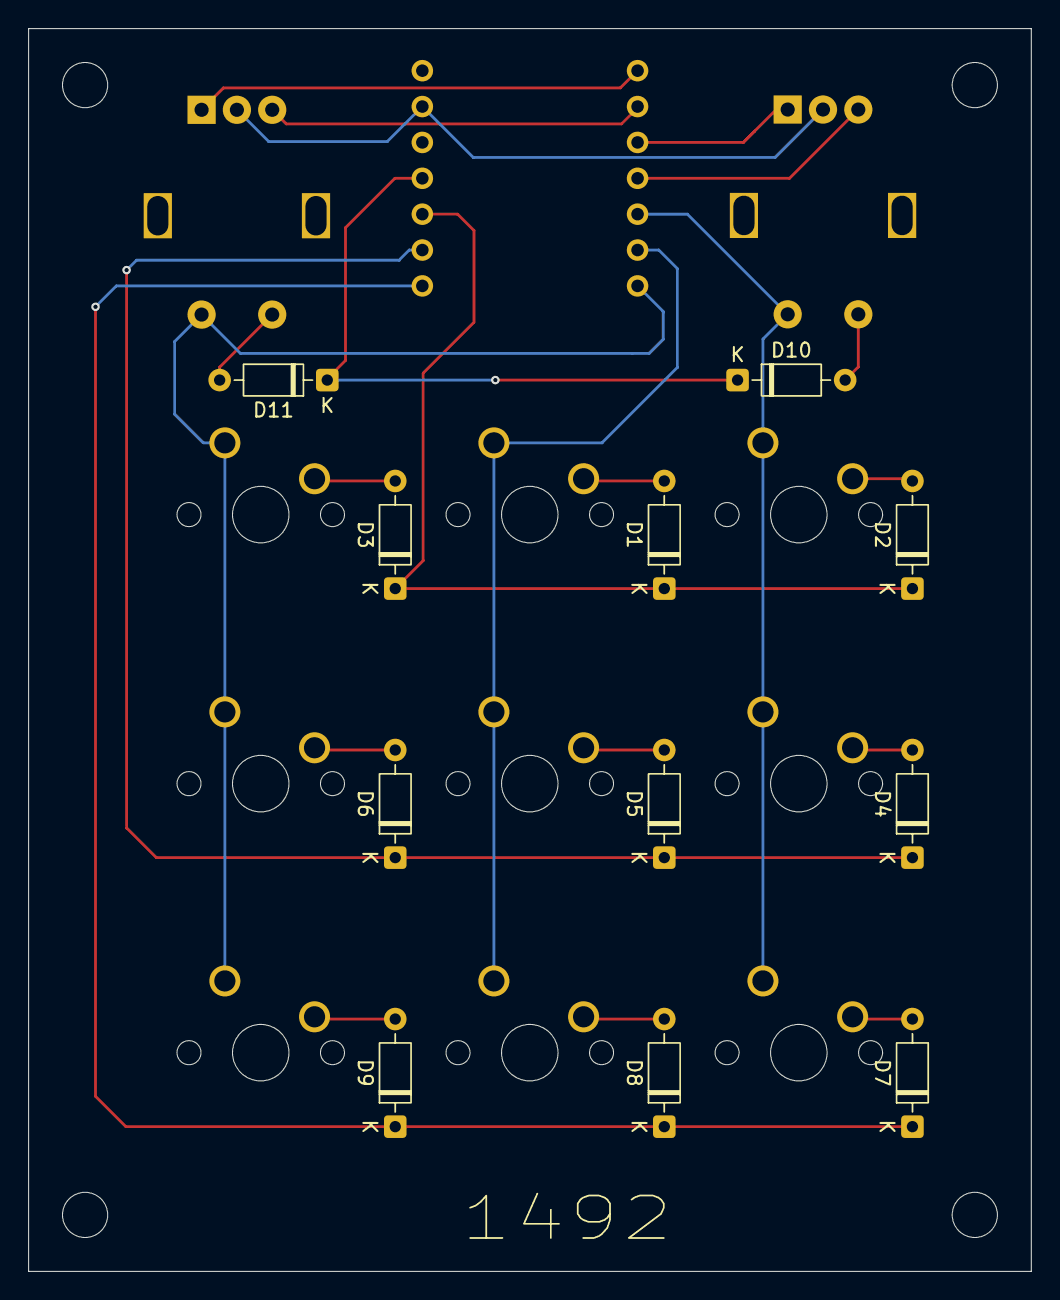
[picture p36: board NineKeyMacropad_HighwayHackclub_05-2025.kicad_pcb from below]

Board: 2 copper layers, 71.0 x 88.0 mm, 23 parts (11 on the bottom side), 23 nets.

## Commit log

2025-07-23 Started BOM
2025-07-28 Add step files for keyboard components
    [Keyboard_Base-V1.step, Keyboard_Lid-V1.step]
2025-07-28 Update BOM
    [BOM.csv]
2025-07-28 Add production files
    [NineKeyMacropad_HighwayHackclub_05-2025.kicad_pcb, NineKeyMacropad_HighwayHackclub_05-2025.kicad_sch]
2025-07-29 Add Headers (Free) to BOM for clarity
2025-07-29 Update BOM.csv with Headers (Free) for clarity
    [BOM.csv]
2025-08-01 Added new case
    [BOM.csv, Base V2 Typewriter.step, Keyboard_Assembled v18.step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]
2025-08-01 Journal the case change
    [BOM.csv]
2025-08-09 Base + Plate for final review
    [Base V2 Typewriter.step, Base V3 Typewriter.step, Keyboard_Assembled v18.step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]
2025-08-09 Final CAD
2025-08-15 Updated production files with Base V4
    [Base V3 Typewriter.step, Base V4 Typewriter.step]
2025-08-15 trying to update CAD
2025-09-23 priced out board assembly (just the diodes)
    [bom.csv, positions.csv]
2025-09-23 caught up Journal and BOM so I can start ordering parts
    [BOM.csv]
2025-09-24 Update BOM.csv with new headers
    [BOM.csv]
